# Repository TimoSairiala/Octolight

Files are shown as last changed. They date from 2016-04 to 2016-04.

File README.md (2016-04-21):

# Octolight
This is a smart night light I have done for my kids.

It has two separate modules
a) under bed unit with RBG leds and motion sensor
b) bedside unit with led strip and push button to increase brightness

Basic functionality is that when ever motion is detected from under the bed (that would be me walking next to the bed)
the RGB leds are turned on with full white color. After motion is not detected, the RBG leds are smoothly dimmed to 
calm blue light that is not too bright for night. When button in bedside unit is pressed, it will turn on led strip in 
bedside unit and maximum white light from RBG leds under the bed.

It is called octolight, because my daughter is a big fan of the tv show and bedside unit has a picture of octonauts.
Octonauts picture is printed on a transparent and the led strip is placed behind this, so it will light up nicely
when the lights are on.

It seems it doesn't help my daughter to get any better sleep, but at least I don't have to stumble across dark room while
walking to her ;)

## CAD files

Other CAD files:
3Dmodels/oktovalo.skp

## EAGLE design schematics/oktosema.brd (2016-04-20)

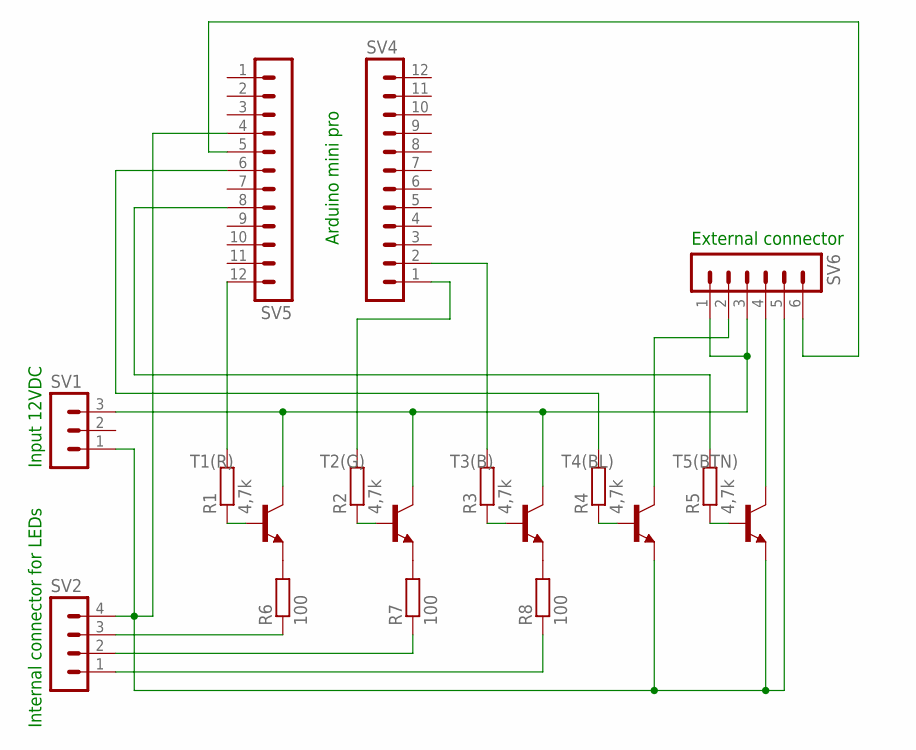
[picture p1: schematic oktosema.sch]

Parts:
R1, R2, R3, R4, R5: 4,7k; 0204/7
R6, R7, R8: 100; 0204/7
SV1: MA03-1
SV2: MA04-1
SV4, SV5: MA12-1
SV6: MA06-1
T1(R), T2(G), T3(B), T4(BL), T5(BTN): BC337-25-NPN-TO92-CBE; TO92-CBE

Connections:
unnamed: R1.1, T1(R).B
unnamed: R2.1, T2(G).B
unnamed: R3.1, T3(B).B
unnamed: R4.1, T4(BL).B
unnamed: R5.1, T5(BTN).B
unnamed: R1.2, SV5.12
unnamed: R2.2, SV4.1
unnamed: R3.2, SV4.2
unnamed: R4.2, SV5.6
unnamed: R5.2, SV5.8
unnamed: SV1.3, SV6.1, SV6.3, T1(R).C, T2(G).C, T3(B).C
unnamed: R6.2, T1(R).E
unnamed: R7.2, T2(G).E
unnamed: R8.2, T3(B).E
unnamed: SV6.4, T5(BTN).C
unnamed: R8.1, SV2.1
unnamed: R6.1, SV2.3
unnamed: R7.1, SV2.2
unnamed: SV6.2, T4(BL).C
unnamed: SV5.5, SV6.6
unnamed: SV1.1, SV2.4, SV5.4, SV6.5, T4(BL).E, T5(BTN).E

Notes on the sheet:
Internal connector for LEDs
External connector
Arduino mini pro
Input 12VDC

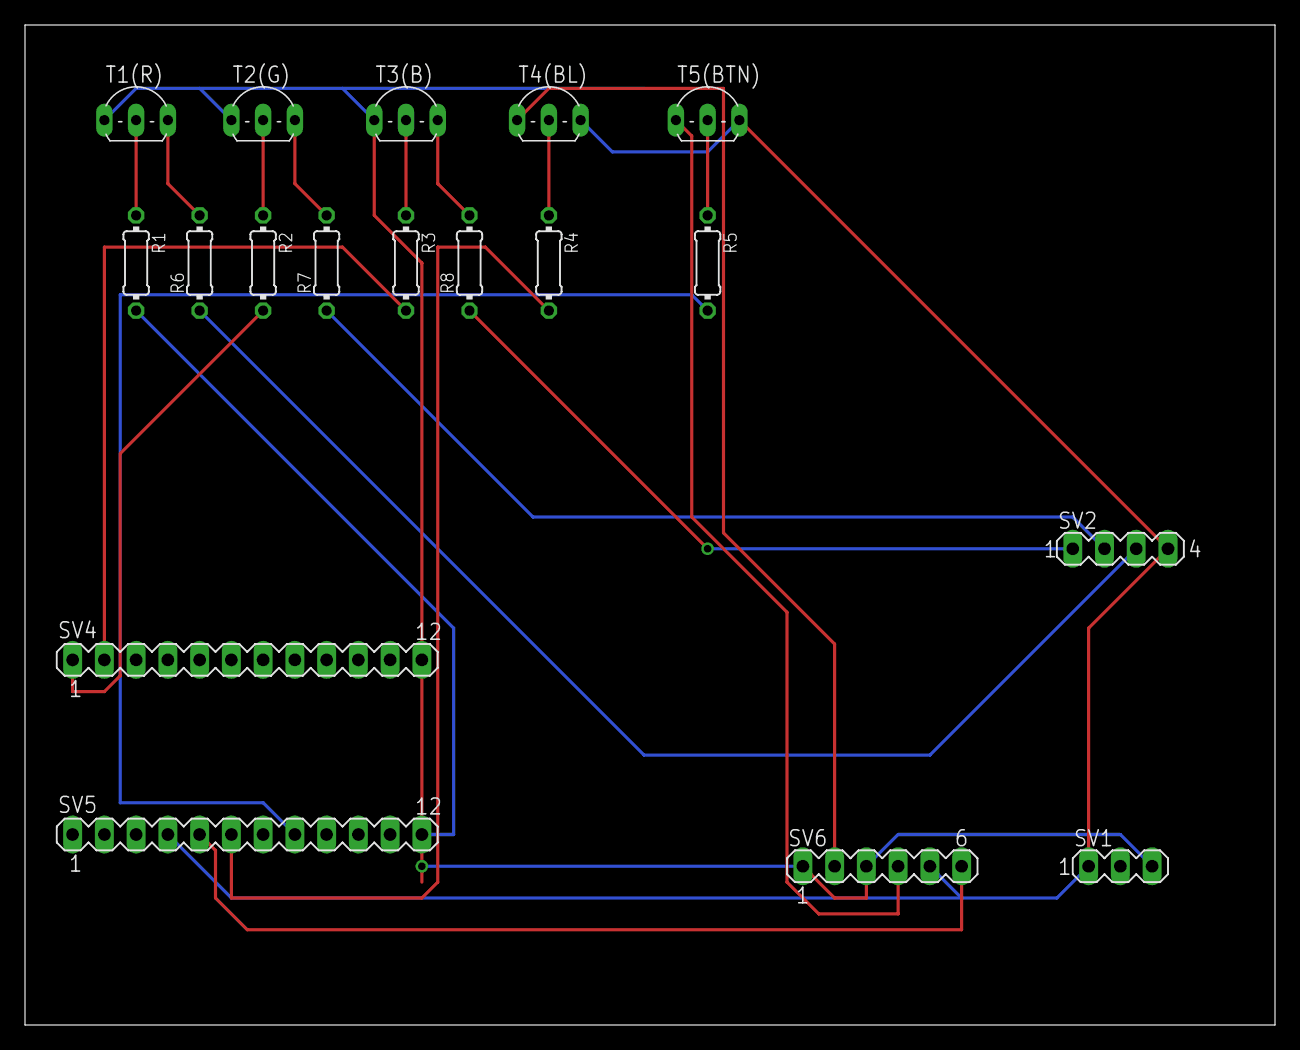
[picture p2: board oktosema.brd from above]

Board: 2 copper layers, 100.0 x 80.0 mm, 18 parts (0 on the bottom side), 21 nets.

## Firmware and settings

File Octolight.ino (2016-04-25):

#include "light.h"

volatile int switchLightsOn = 0;
Light *oktovalo;

void setup() {
  Serial.begin( 9600 );
  Serial.println( "Welcome to Oktovalo" );
  oktovalo = new Light( );
  switchLightsOn = 1;

  // interrupt 0 equals to input pin 2 on uno and mini
  // see http://arduino.cc/en/Reference/attachInterrupt

  // int0 will have the push button
  attachInterrupt( 0, lightsOn, CHANGE );

  // int1 will have motion detector
  attachInterrupt( 1, lightsOn, RISING );
}

void loop() {
  if( switchLightsOn ) {
    switchLightsOn = 0;
    Serial.println("oktovalo main looper Switch lights on");
    oktovalo->SwitchOn( );
  }
  if( oktovalo->Active( ) ) {
    oktovalo->Update( );
  }
}

void lightsOn( ) {
  // Don't print in ISR, just for debugging
  // Serial.println( "octointerrupt" );
  switchLightsOn = 1;
}

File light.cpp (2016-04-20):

#include "Light.h"

Light::Light( ) {
  Serial.println( "Light::Light" );
  pinMode( this->_buttonBackLightPin, OUTPUT );
  pinMode( this->_backLightPin, OUTPUT );
  pinMode( this->_redPin, OUTPUT );
  pinMode( this->_greenPin, OUTPUT );
  pinMode( this->_bluePin, OUTPUT );
  pinMode( this->_statusPin, OUTPUT );
  // this pullup to be removed?
  pinMode( this->_buttonPin, INPUT_PULLUP );

  this->_backLightCurrent = 255;
  this->_buttonBackLightCurrent = 255;
  this->_redCurrent = 0;
  this->_greenCurrent = 0;
  this->_blueCurrent = 128;

  WriteOutput( );
}

void Light::SwitchOn( ) {
  Serial.println("Light::SwitchOn switching lights on");
  this->_backLightCurrent = 255;
  this->_buttonBackLightCurrent = 255;
  this->_redCurrent = 255;
  this->_greenCurrent = 255;
  this->_blueCurrent = 255;

  // first lastupdate will be in the future to enable smooth delay
  this->_timeOfLastUpdate = millis( ) + this->_delayBeforeDimming;
}

void Light::Update( ) {
  unsigned long currentMillis = millis();
/*
  Serial.print( "Active: " );
  Serial.print( Active( ) );
  Serial.print( " currentMillis: " );
  Serial.print( currentMillis );
  Serial.print( " lastUpdate: " );
  Serial.println( this->_timeOfLastUpdate );
*/
  if( Active( ) &&
    ((unsigned long)(currentMillis - this->_timeOfLastUpdate ) >= this->_updateDelay ) ) {
    if( this->_backLightCurrent > this->_backLightNormal ) this->_backLightCurrent --;
    else if( this->_backLightCurrent < this->_backLightNormal ) this->_backLightCurrent ++;
    if( this->_buttonBackLightCurrent > this->_buttonBackLightNormal ) this->_buttonBackLightCurrent --;
    else if( this->_buttonBackLightCurrent < this->_buttonBackLightNormal ) this->_buttonBackLightCurrent ++;
    if( this->_redCurrent > this->_redNormal ) this->_redCurrent --;
    else if( this->_redCurrent < this->_redNormal ) this->_redCurrent ++;
    if( this->_greenCurrent > this->_greenNormal) this->_greenCurrent --;
    else if( this->_greenCurrent < this->_greenNormal) this->_greenCurrent ++;
    if( this->_blueCurrent > this->_blueNormal) this->_blueCurrent --;
    else if( this->_blueCurrent < this->_blueNormal) this->_blueCurrent ++;
    
    this->_timeOfLastUpdate = millis( );
    WriteOutput( );
  }
}

bool Light::Active( ) {
//  Serial.println("Light::Active checking if light is alerady active");
/* Serial.print( "backlight: " );
Serial.println( this->_backLightCurrent );
Serial.print( "red: " );
Serial.println( this->_redCurrent );
Serial.print( "green: " );
Serial.println( this->_greenCurrent );
Serial.print( "blue: " );
Serial.println( this->_blueCurrent ); */

  if( _backLightCurrent != this->_backLightNormal ||
      _buttonBackLightCurrent != this->_buttonBackLightNormal ||
      _redCurrent != this->_redNormal ||
      _greenCurrent != this->_greenNormal ||
      _blueCurrent != this->_blueNormal )
        return true;
  else
    return false;
}

void Light::WriteOutput( ) {
  Serial.print( "backlight: " );
  Serial.print( this->_backLightCurrent );
  Serial.print( " red: " );
  Serial.print( this->_redCurrent );
  Serial.print( " blue: " );
  Serial.print( this->_blueCurrent );
  Serial.print( " green: " );
  Serial.println( this->_greenCurrent );
  
  analogWrite( this->_backLightPin, this->_backLightCurrent );
  analogWrite( this->_buttonBackLightPin, this->_buttonBackLightCurrent );
  analogWrite( this->_redPin, this->_redCurrent );
  analogWrite( this->_bluePin, this->_blueCurrent );
  analogWrite( this->_greenPin, this->_greenCurrent );
  analogWrite( this->_statusPin, Active( ) );
}

bool Light::ButtonPressed( ) {
  // with INPUT_PULLUP value is false when button is pressed
  if(! digitalRead( _buttonPin ) )
    return true;
  else return false;
}

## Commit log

2015-02-13 Initial commit
    Basic octolight functionality.
    It waits for interrupt in pin 2 switching on lights, then dimming those
    gradually.
2015-02-28 Add button backlight
2015-10-06 Using analogWrite instead of digital
    This enabled pwm output for smooth controlling and fading
    of the lights
2016-04-06 3D model to print octolight
    This is box with arduino pro mini holder and space for additional
    electronics. It has hole in each wall for rub leds. One wall has
    additional hole for PIR sensor and another wall has holes for power
    cable and wall unit connector.
    [oktovalo.skp]
2016-04-19 Debugging easierify aka light on while power on and some debug prints
2016-04-20 Add schematics draft
    [oktosema.brd, oktosema.sch]
2016-04-20 fix delay before dimming
    [light.cpp, light.h]
2016-04-26 Make arduino holder little bit bigger and increase tolerances
    [oktovalo.skp]
2016-04-26 to help 3D printing, change octonaut logo to another side of the lid
    [oktovalo.skp]
2016-04-26 fix couple of faces inside out
    [oktovalo.skp]
2016-04-28 increase led hole sizes
    [oktovalo.skp]
